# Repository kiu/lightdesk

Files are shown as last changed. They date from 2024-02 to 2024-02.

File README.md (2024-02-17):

# lightdesk

Custom desk light and RGB strip controller

Superseded by [https://github.com/kiu/kha](https://github.com/kiu/kha)

## Photos

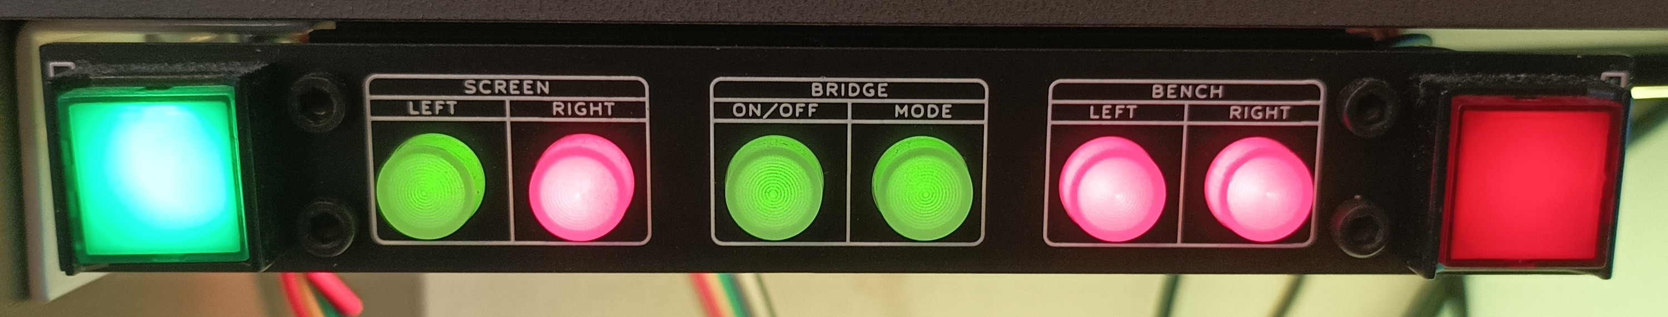
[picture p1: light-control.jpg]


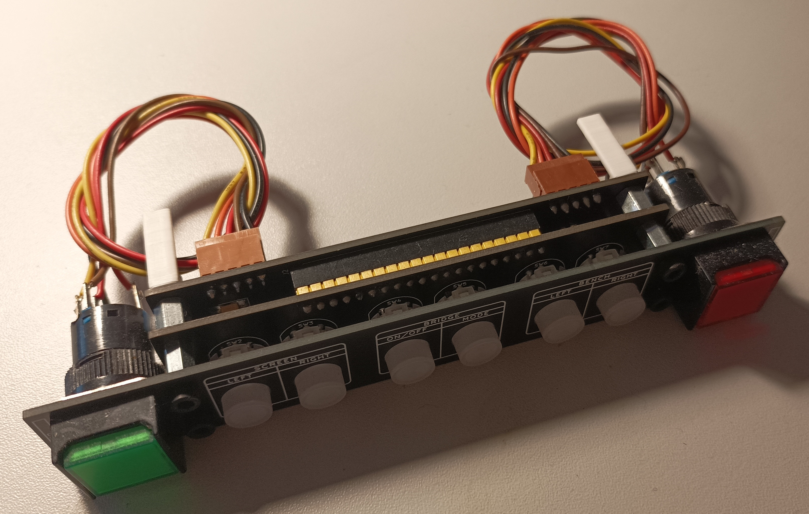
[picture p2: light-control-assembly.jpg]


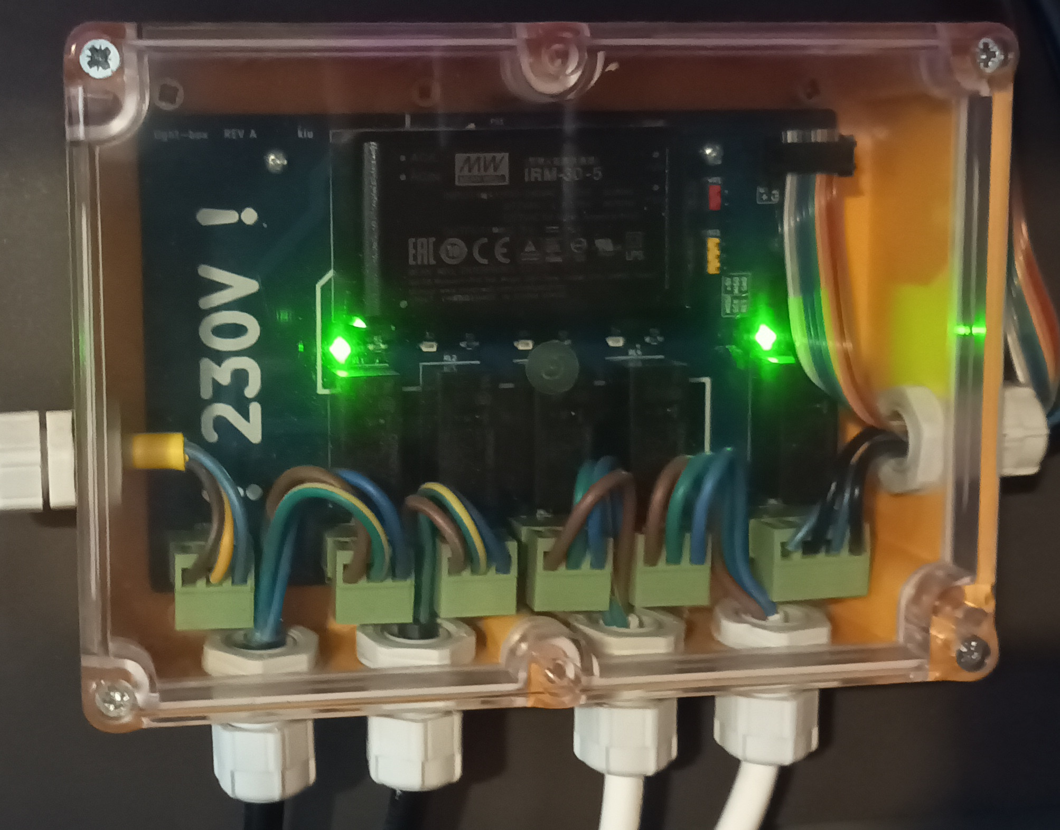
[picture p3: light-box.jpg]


## Render

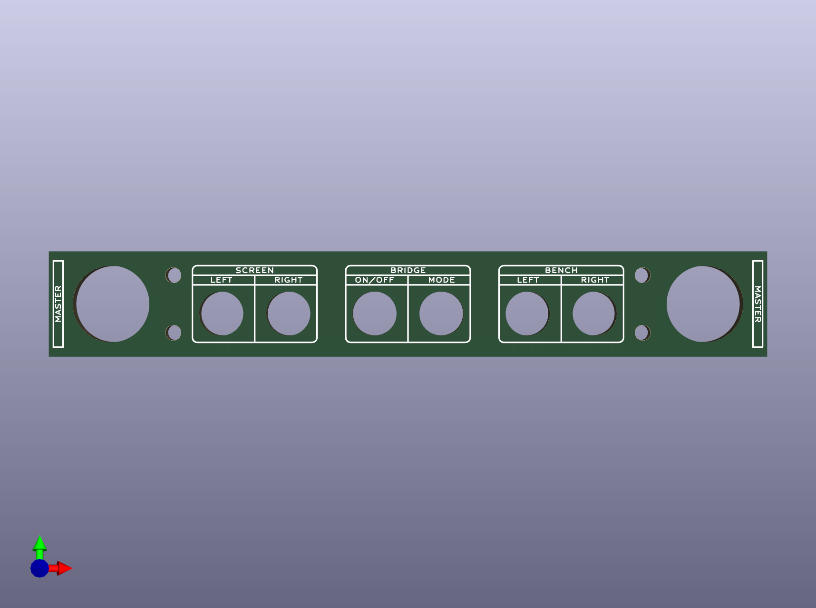
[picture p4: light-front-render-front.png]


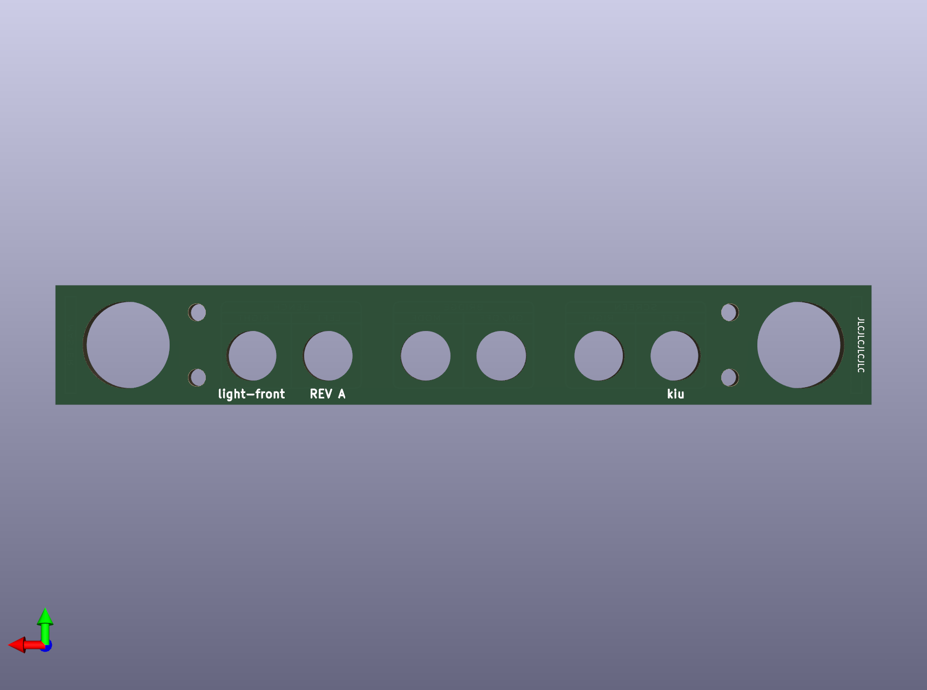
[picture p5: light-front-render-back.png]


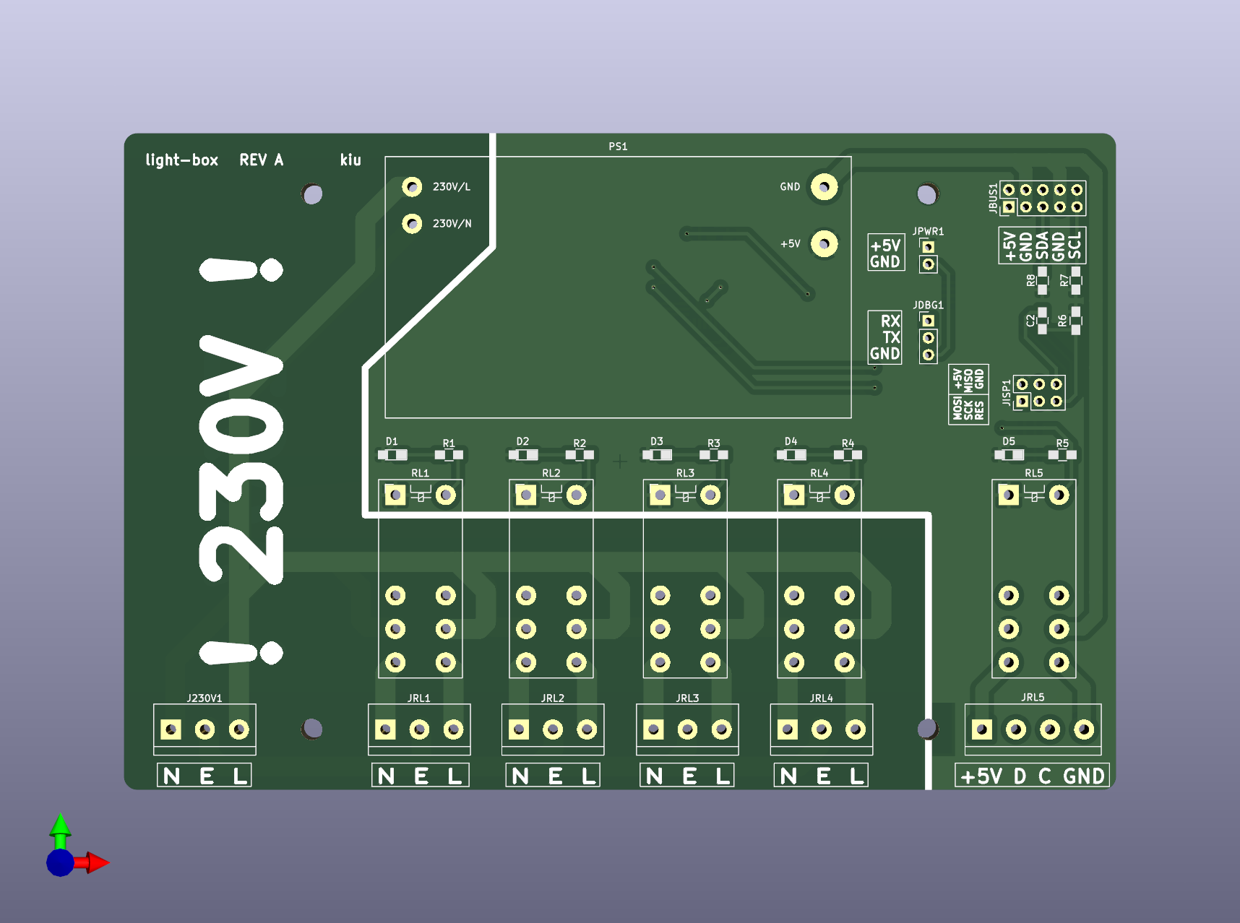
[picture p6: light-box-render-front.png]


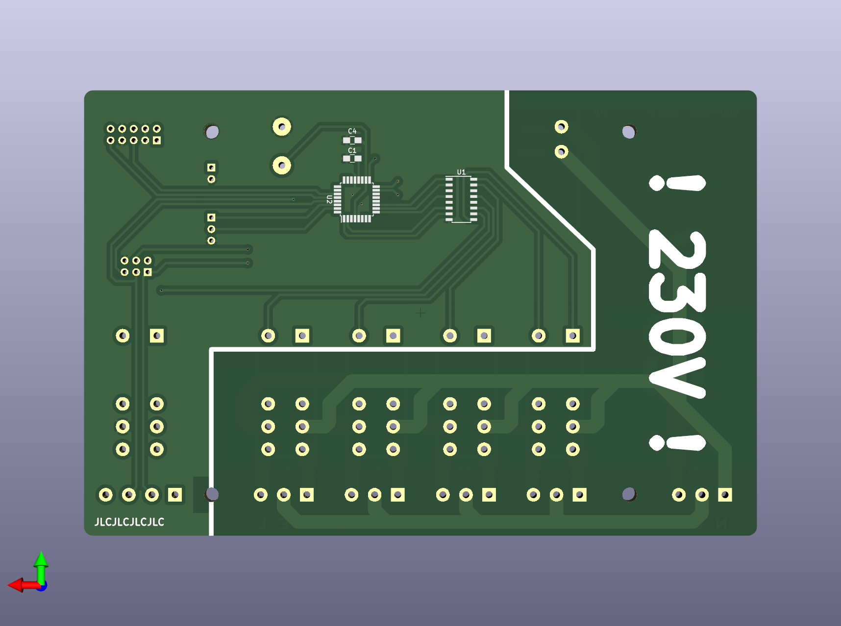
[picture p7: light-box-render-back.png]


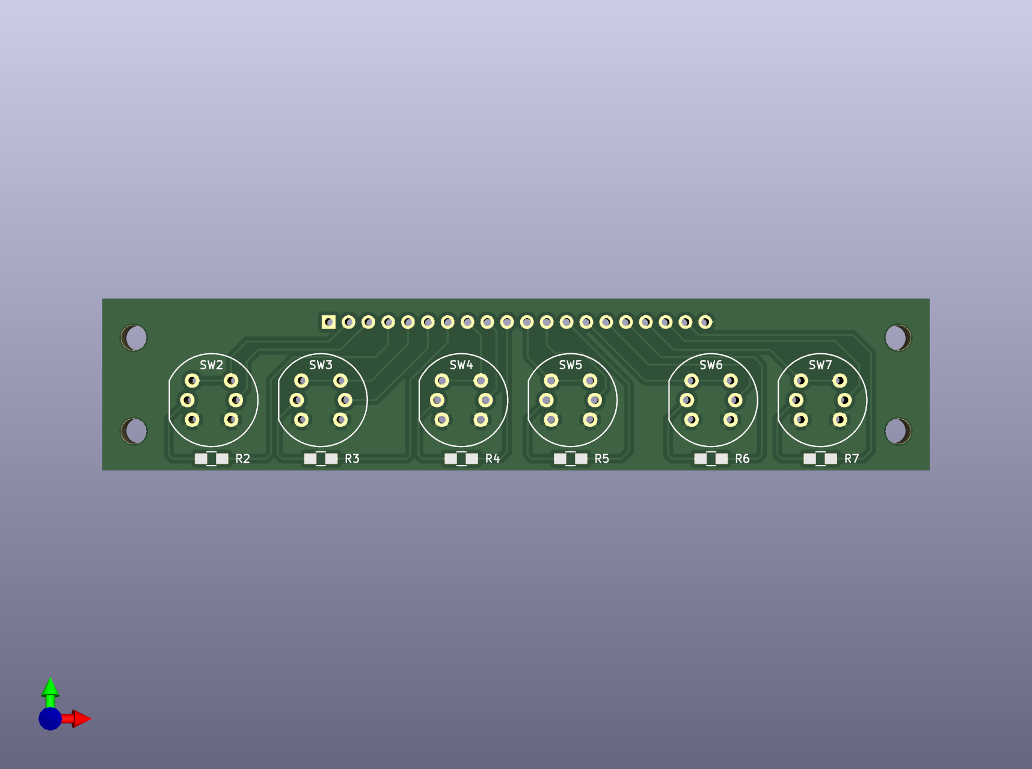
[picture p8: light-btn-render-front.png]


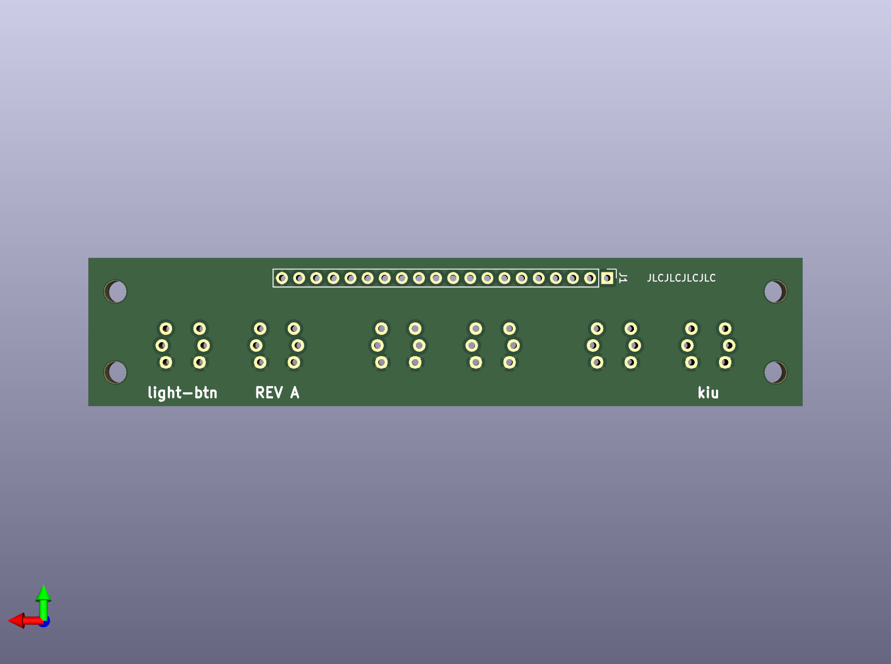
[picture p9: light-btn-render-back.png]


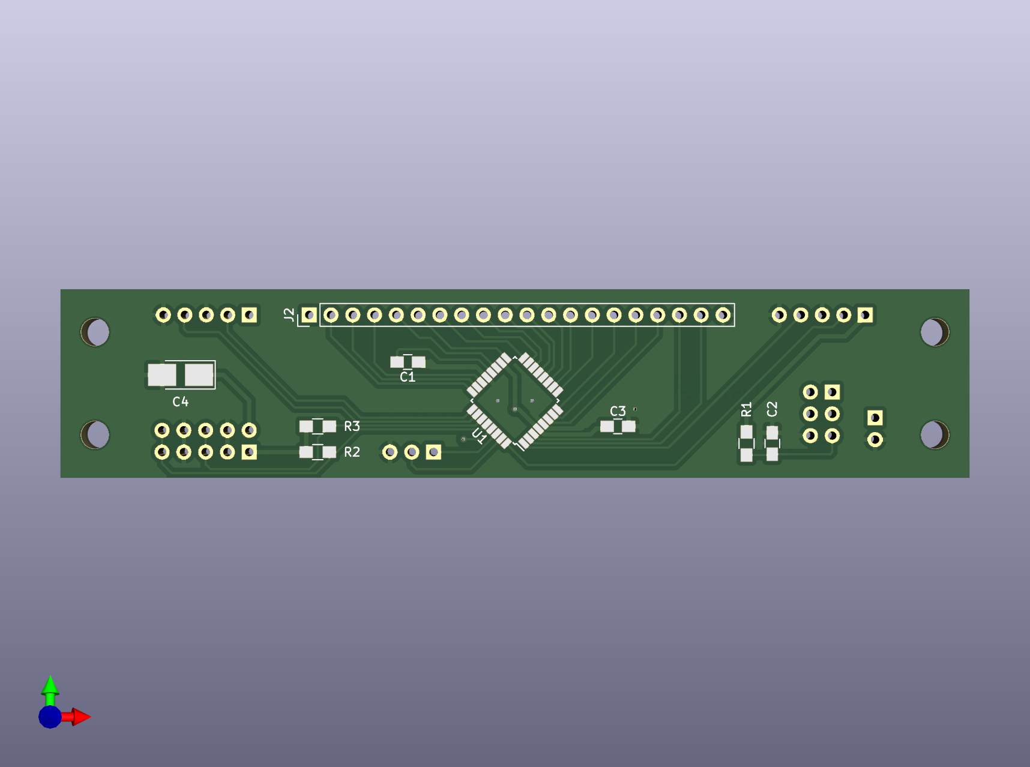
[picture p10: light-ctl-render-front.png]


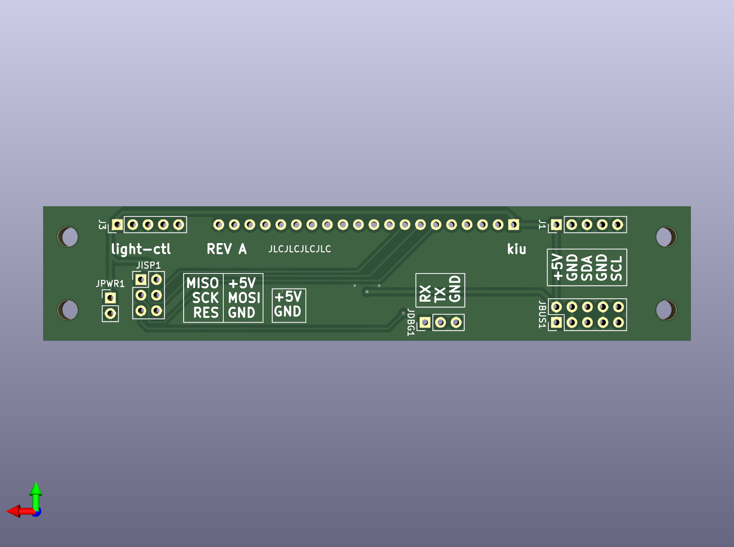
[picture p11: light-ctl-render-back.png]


# License

This project is licensed under the Creative Commons Attribution-NonCommercial 3.0 Unported (CC BY-NC 3.0) license.

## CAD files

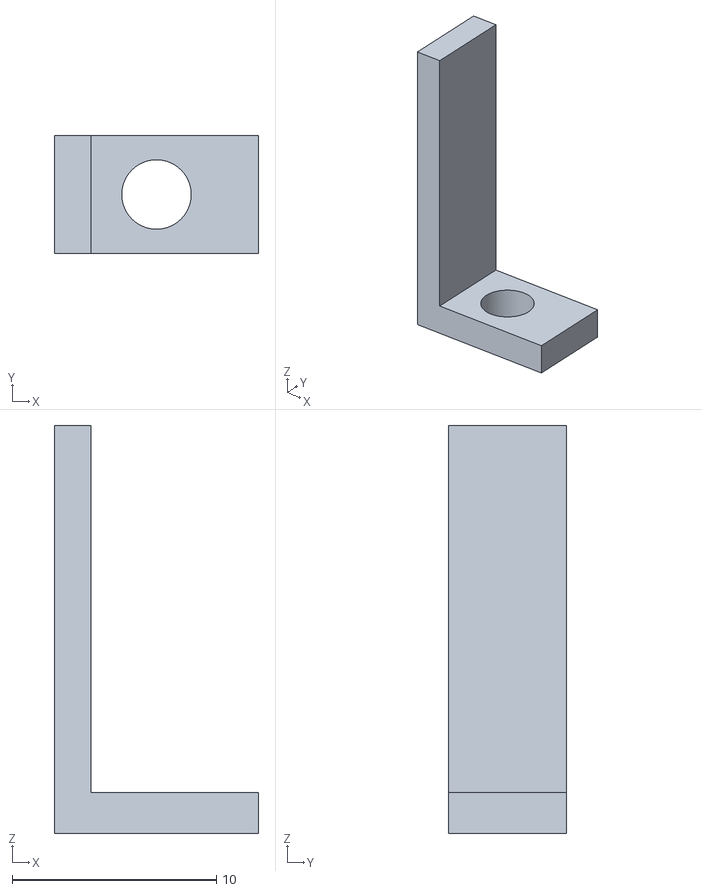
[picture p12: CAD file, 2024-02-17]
mechanical/desklight-a.stl
10.0 x 5.80 x 20.0

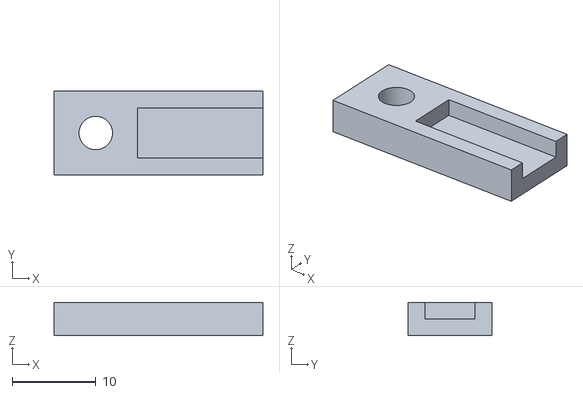
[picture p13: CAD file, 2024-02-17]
mechanical/desklight-b.stl
25.0 x 10.0 x 4.00

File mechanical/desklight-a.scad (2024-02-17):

difference () {
    translate([0, -2.9, 0]) { 
        cube([10, 5.8, 2]);
    }

    translate([5, 0, 0]) { 
        cylinder(h=15, r=1.7, $fn = 360, center=true);
    }
}

translate([0, -2.9, 0]) {
    cube([1.8, 5.8, 20]);  
}

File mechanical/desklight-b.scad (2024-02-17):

difference () {
    translate([0, -5, 0]) { 
        cube([25, 10, 4]);
    }

    translate([5, 0, 0]) { 
        cylinder(h=15, d=4, $fn = 360, center=true);
    }
    
//    translate([5, 0, 0]) { 
//        cylinder(h=3, r1=3.5, r2=1.3, $fn = 360, center=true);
//    }
    
    
    translate([10, -3, 2]) { 
        cube([16, 6, 3]);
    }
}

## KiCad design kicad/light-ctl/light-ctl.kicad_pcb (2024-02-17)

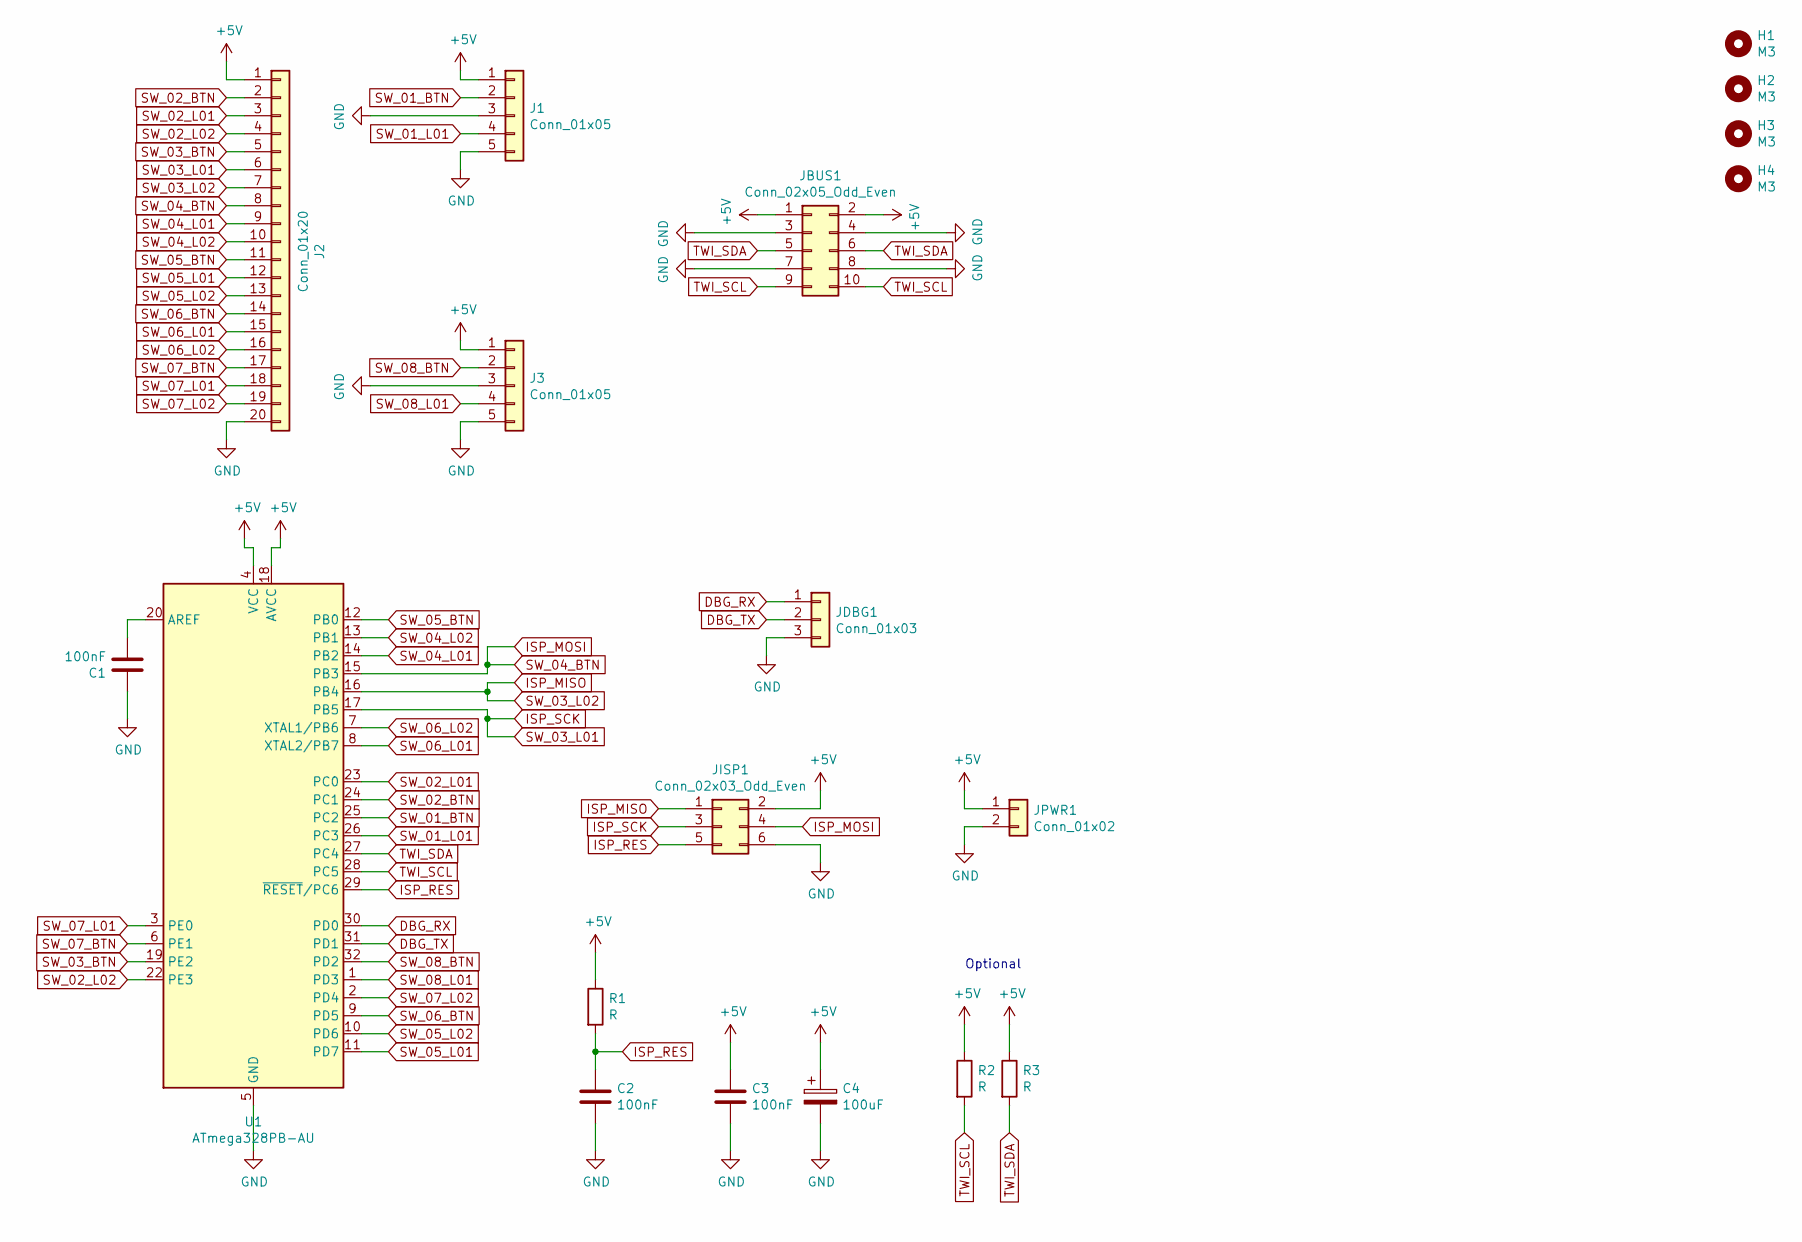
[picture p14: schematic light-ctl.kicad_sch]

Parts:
C1, C2, C3: 100nF; C_0805_HandSoldering
C4: 100uF; CP_Tantalum_Case-B_EIA-3528-21_Hand
H1, H2, H3, H4: M3; MountingHole_3.2mm_M3_DIN965
J1, J3: Conn_01x05; Pin_Header_Straight_1x05_Pitch2.54mm
J2: Conn_01x20; Pin_Header_Straight_1x20_Pitch2.54mm
JBUS1: Conn_02x05_Odd_Even; Pin_Header_Straight_2x05_Pitch2.54mm
JDBG1: Conn_01x03; Pin_Header_Straight_1x03_Pitch2.54mm
JISP1: Conn_02x03_Odd_Even; Pin_Header_Straight_2x03_Pitch2.54mm
JPWR1: Conn_01x02; Pin_Header_Straight_1x02_Pitch2.54mm
R1, R2, R3: R; R_0805_HandSoldering
U1: ATmega328PB-AU; LQFP-32_7x7mm_Pitch0.8mm

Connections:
+5V: C3.1, C4.1, J1.1, J2.1, J3.1, JBUS1.1, JBUS1.2, JISP1.2, JPWR1.1, R1.1, R2.1, R3.1, U1.4 (VCC), U1.18 (AVCC)
DBG_RX: JDBG1.1, U1.30 (PD0)
DBG_TX: JDBG1.2, U1.31 (PD1)
GND: C1.1, C2.2, C3.2, C4.2, J1.3, J1.5, J2.20, J3.3, J3.5, JBUS1.3, JBUS1.4, JBUS1.7, JBUS1.8, JDBG1.3, JISP1.6, JPWR1.2, U1.5 (GND), U1.21 (GND)
ISP_MISO: J2.7, JISP1.1, U1.16 (PB4)
ISP_MOSI: J2.8, JISP1.4, U1.15 (PB3)
ISP_RES: C2.1, JISP1.5, R1.2, U1.29 (~RESET/PC6)
ISP_SCK: J2.6, JISP1.3, U1.17 (PB5)
unnamed: C1.2, U1.20 (AREF)
SW_01_BTN: J1.2, U1.25 (PC2)
SW_01_L01: J1.4, U1.26 (PC3)
SW_02_BTN: J2.2, U1.24 (PC1)
SW_02_L01: J2.3, U1.23 (PC0)
SW_02_L02: J2.4, U1.22 (PE3)
SW_03_BTN: J2.5, U1.19 (PE2)
SW_04_L01: J2.9, U1.14 (PB2)
SW_04_L02: J2.10, U1.13 (PB1)
SW_05_BTN: J2.11, U1.12 (PB0)
SW_05_L01: J2.12, U1.11 (PD7)
SW_05_L02: J2.13, U1.10 (PD6)
SW_06_BTN: J2.14, U1.9 (PD5)
SW_06_L01: J2.15, U1.8 (XTAL2/PB7)
SW_06_L02: J2.16, U1.7 (XTAL1/PB6)
SW_07_BTN: J2.17, U1.6 (PE1)
SW_07_L01: J2.18, U1.3 (PE0)
SW_07_L02: J2.19, U1.2 (PD4)
SW_08_BTN: J3.2, U1.32 (PD2)
SW_08_L01: J3.4, U1.1 (PD3)
TWI_SCL: JBUS1.9, JBUS1.10, R2.2, U1.28 (PC5)
TWI_SDA: JBUS1.5, JBUS1.6, R3.2, U1.27 (PC4)

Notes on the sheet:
Optional

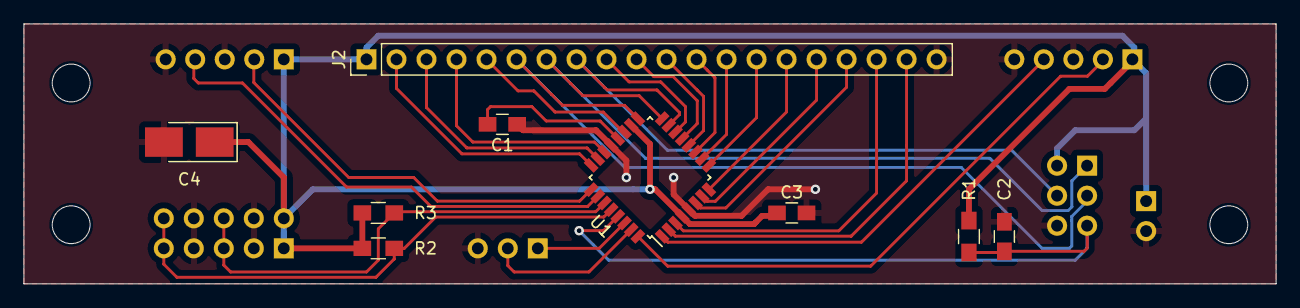
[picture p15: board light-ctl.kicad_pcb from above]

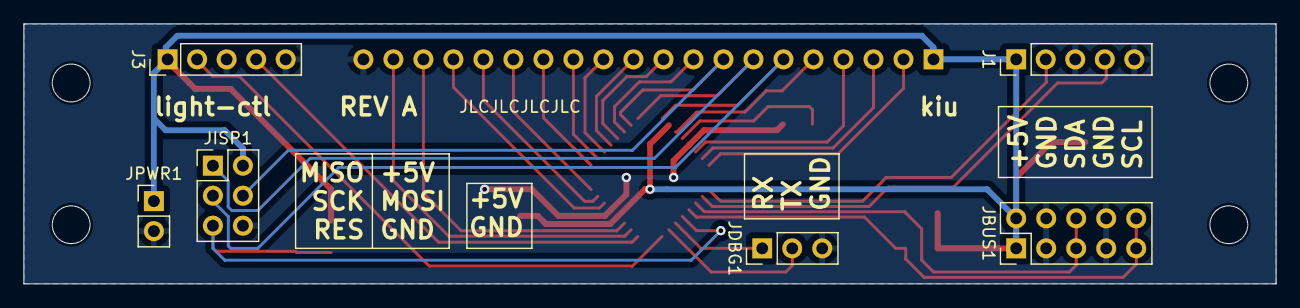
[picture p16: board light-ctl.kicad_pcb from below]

Board: 2 copper layers, 106.0 x 22.0 mm, 19 parts (6 on the bottom side), 30 nets.

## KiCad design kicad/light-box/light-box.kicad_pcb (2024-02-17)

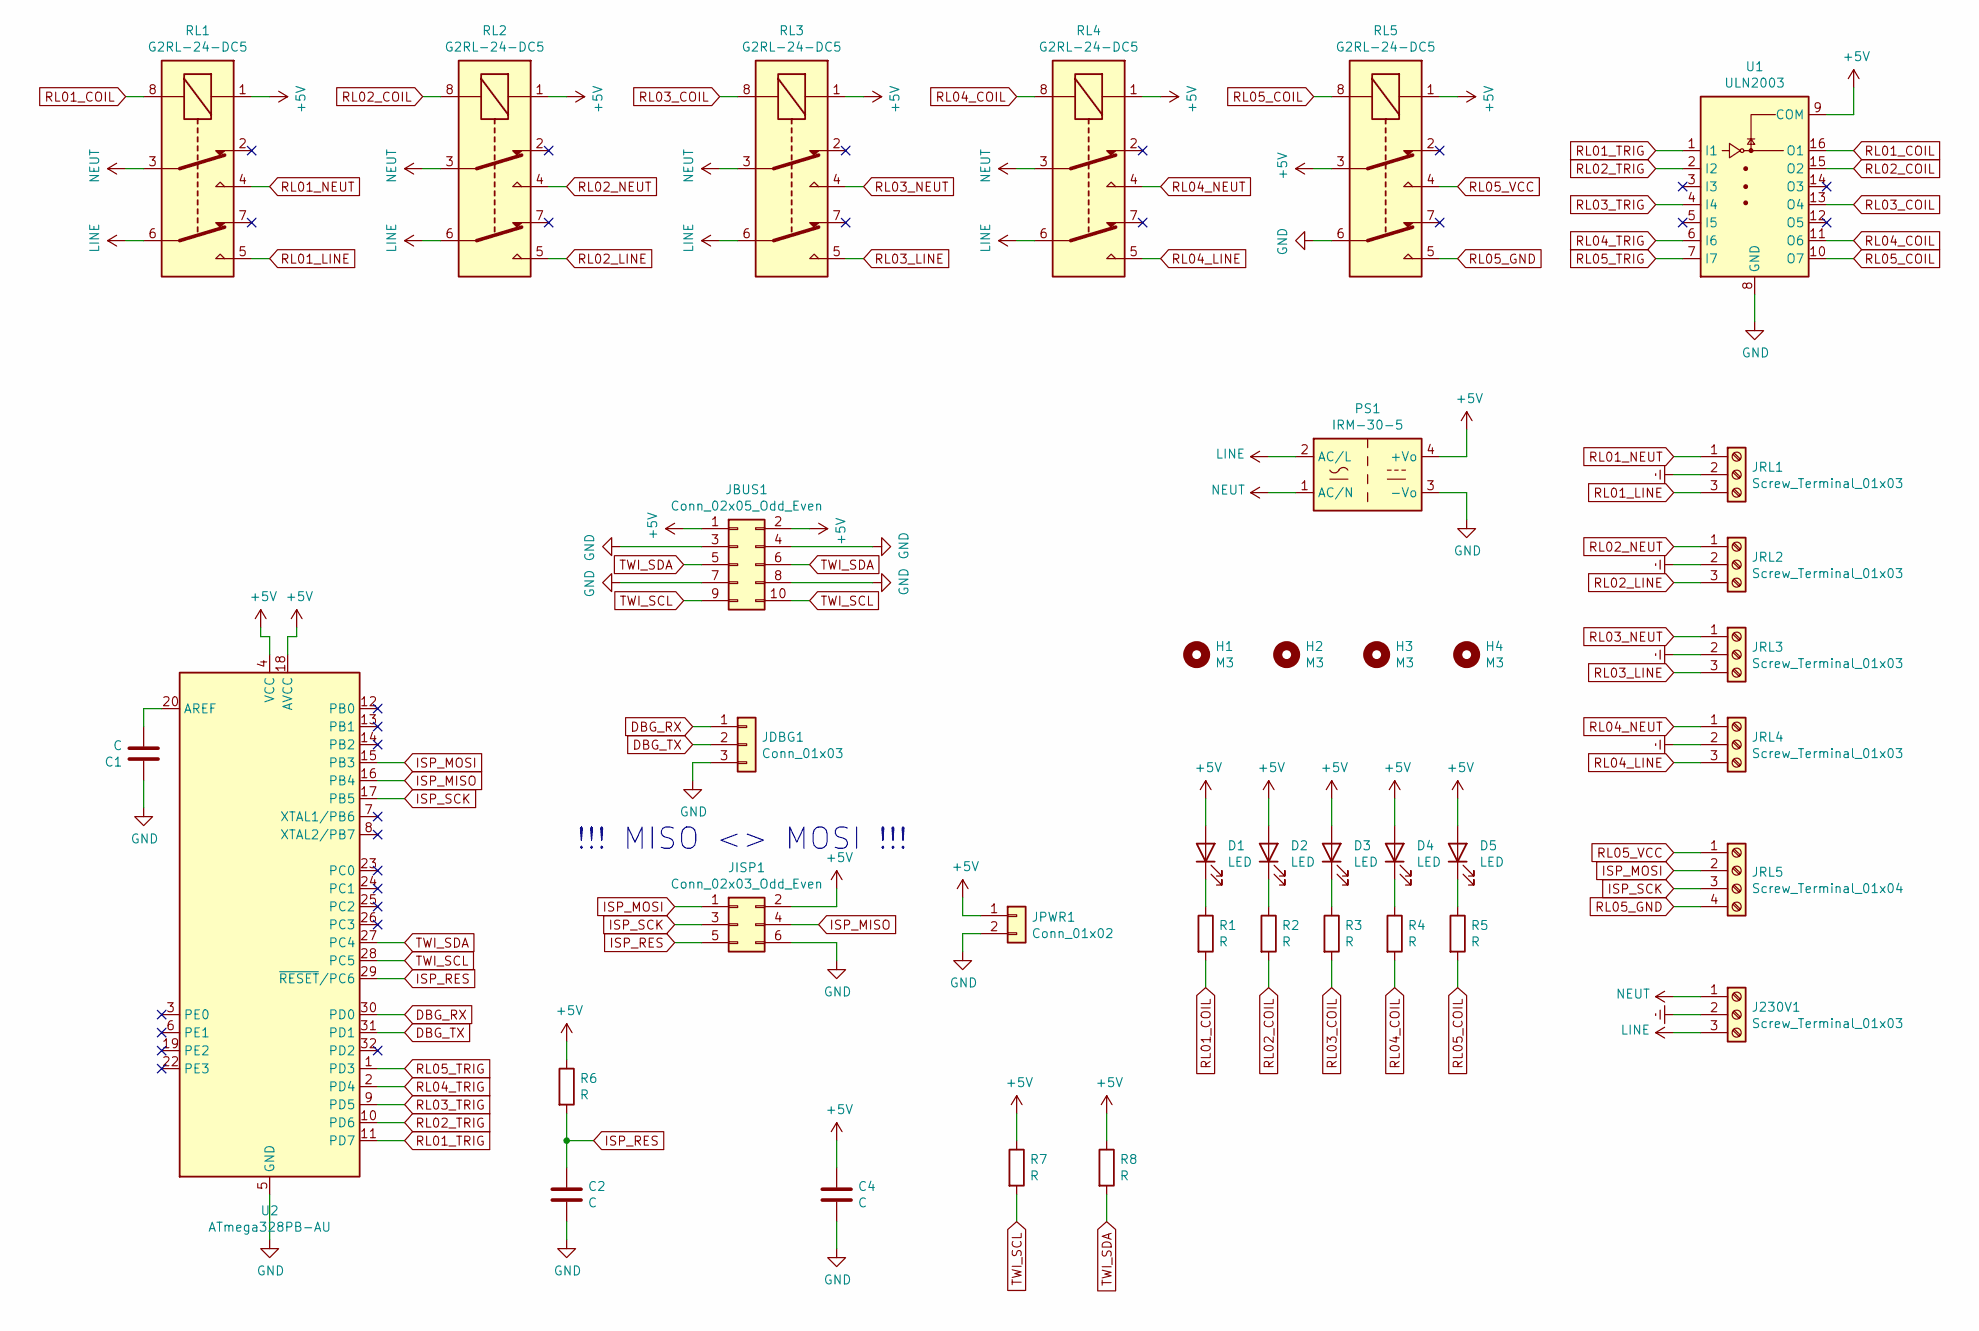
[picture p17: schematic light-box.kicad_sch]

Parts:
C1, C2, C4: C; C_0805_HandSoldering
D1, D2, D3, D4, D5: LED; LED_0805_HandSoldering
H1, H2, H3, H4: M3; MountingHole_3.2mm_M3_DIN965
J230V1: Screw_Terminal_01x03; TerminalBlock_bornier-3_P5.08mm
JBUS1: Conn_02x05_Odd_Even; Pin_Header_Straight_2x05_Pitch2.54mm
JDBG1: Conn_01x03; Pin_Header_Straight_1x03_Pitch2.54mm
JISP1: Conn_02x03_Odd_Even; Pin_Header_Straight_2x03_Pitch2.54mm
JPWR1: Conn_01x02; Pin_Header_Straight_1x02_Pitch2.54mm
JRL1, JRL2, JRL3, JRL4: Screw_Terminal_01x03; TerminalBlock_bornier-3_P5.08mm
JRL5: Screw_Terminal_01x04; TerminalBlock_bornier-4_P5.08mm
PS1: IRM-30-5; ACDC-Conv_MeanWell-IRM-30-XX
R1, R2, R3, R4, R5, R6, R7, R8: R; R_0805_HandSoldering
RL1, RL2, RL3, RL4, RL5: G2RL-24-DC5; Relay_DPDT_Omron_G2RL-24
U1: ULN2003; SOIC-16_3.9x9.9mm_Pitch1.27mm
U2: ATmega328PB-AU; TQFP-32_7x7mm_Pitch0.8mm

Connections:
+5V: C4.1, D1.2 (A), D2.2 (A), D3.2 (A), D4.2 (A), D5.2 (A), JBUS1.1, JBUS1.2, JISP1.2, JPWR1.1, PS1.4 (+Vo), R6.1, R7.1, R8.1, RL1.1, RL2.1, RL3.1, RL4.1, RL5.1, RL5.3, U1.9 (COM), U2.4 (VCC), U2.18 (AVCC)
DBG_RX: JDBG1.1, U2.30 (PD0)
DBG_TX: JDBG1.2, U2.31 (PD1)
Earth: J230V1.2, JRL1.2, JRL2.2, JRL3.2, JRL4.2
GND: C1.1, C2.2, C4.2, JBUS1.3, JBUS1.4, JBUS1.7, JBUS1.8, JDBG1.3, JISP1.6, JPWR1.2, PS1.3 (-Vo), RL5.6, U1.8 (GND), U2.5 (GND), U2.21 (GND)
ISP_MISO: JISP1.4, U2.16 (PB4)
ISP_MOSI: JISP1.1, JRL5.2, U2.15 (PB3)
ISP_RES: C2.1, JISP1.5, R6.2, U2.29 (~RESET/PC6)
ISP_SCK: JISP1.3, JRL5.3, U2.17 (PB5)
LINE: J230V1.3, PS1.2 (AC/L), RL1.6, RL2.6, RL3.6, RL4.6
NEUT: J230V1.1, PS1.1 (AC/N), RL1.3, RL2.3, RL3.3, RL4.3
unnamed: C1.2, U2.20 (AREF)
unnamed: D1.1 (K), R1.1
unnamed: D2.1 (K), R2.1
unnamed: D3.1 (K), R3.1
unnamed: D4.1 (K), R4.1
unnamed: D5.1 (K), R5.1
RL01_COIL: R1.2, RL1.8, U1.16 (O1)
RL01_LINE: JRL1.3, RL1.5
RL01_NEUT: JRL1.1, RL1.4
RL01_TRIG: U1.1 (I1), U2.11 (PD7)
RL02_COIL: R2.2, RL2.8, U1.15 (O2)
RL02_LINE: JRL2.3, RL2.5
RL02_NEUT: JRL2.1, RL2.4
RL02_TRIG: U1.2 (I2), U2.10 (PD6)
RL03_COIL: R3.2, RL3.8, U1.13 (O4)
RL03_LINE: JRL3.3, RL3.5
RL03_NEUT: JRL3.1, RL3.4
RL03_TRIG: U1.4 (I4), U2.9 (PD5)
RL04_COIL: R4.2, RL4.8, U1.11 (O6)
RL04_LINE: JRL4.3, RL4.5
RL04_NEUT: JRL4.1, RL4.4
RL04_TRIG: U1.6 (I6), U2.2 (PD4)
RL05_COIL: R5.2, RL5.8, U1.10 (O7)
RL05_GND: JRL5.4, RL5.5
RL05_TRIG: U1.7 (I7), U2.1 (PD3)
RL05_VCC: JRL5.1, RL5.4
TWI_SCL: JBUS1.9, JBUS1.10, R7.2, U2.28 (PC5)
TWI_SDA: JBUS1.5, JBUS1.6, R8.2, U2.27 (PC4)

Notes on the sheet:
!!! MISO <> MOSI !!!

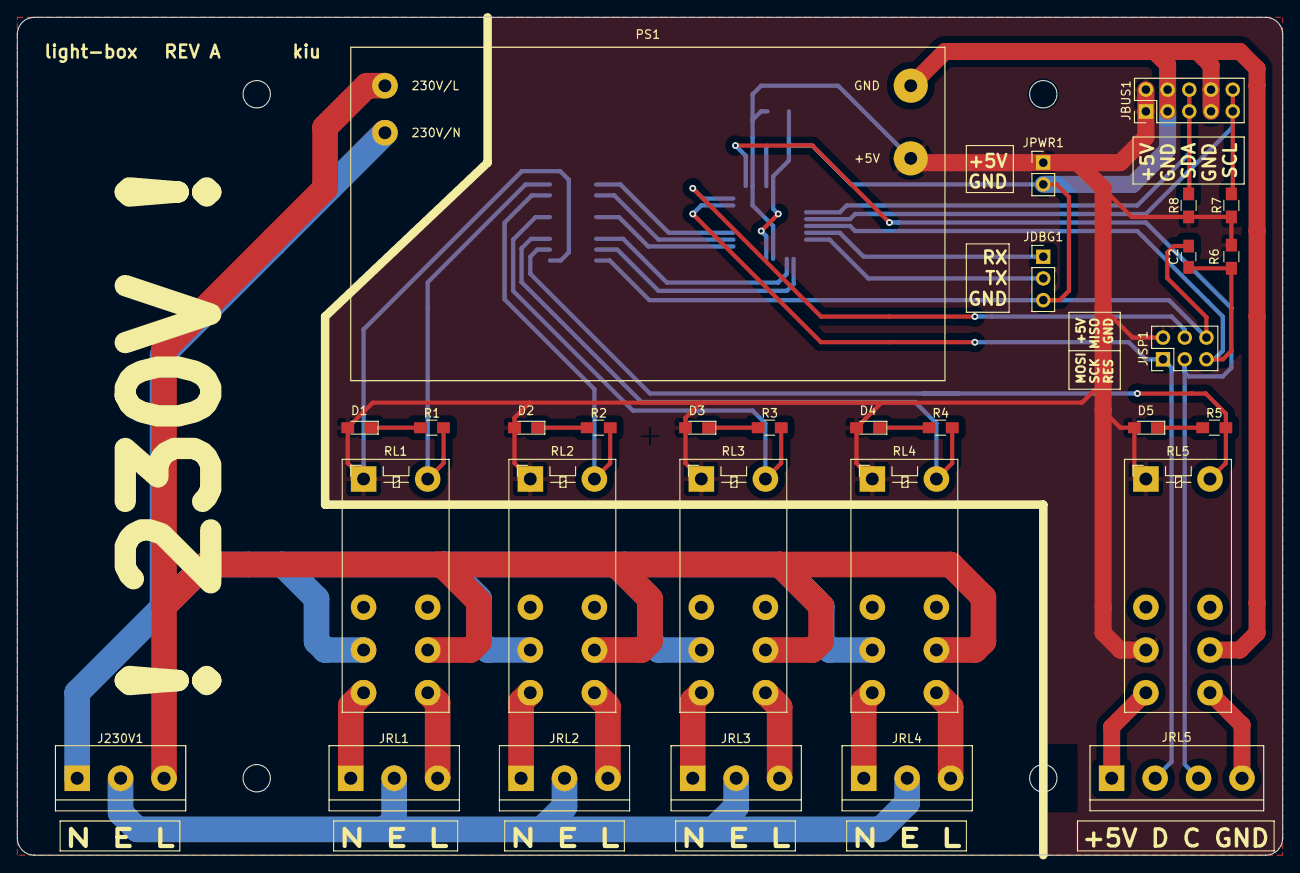
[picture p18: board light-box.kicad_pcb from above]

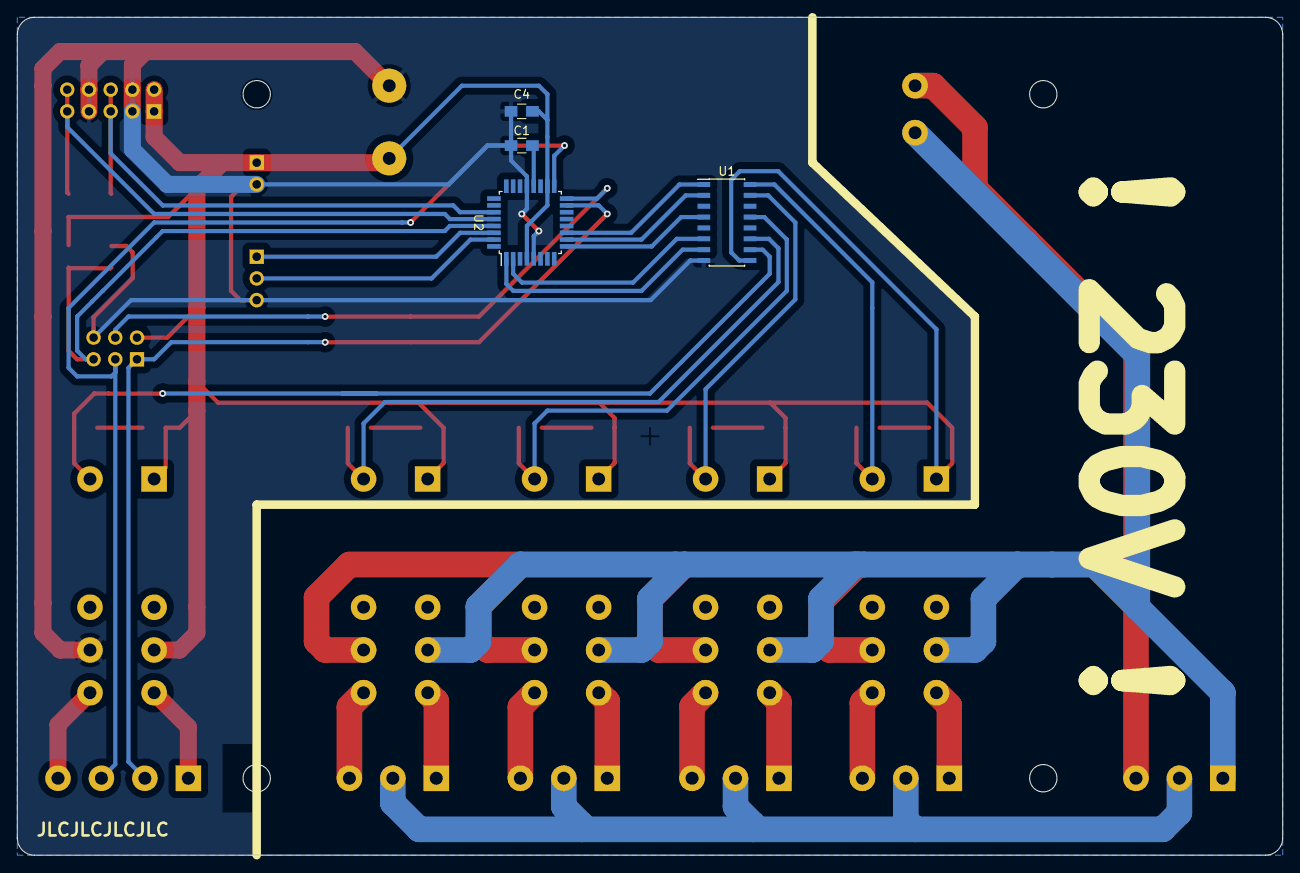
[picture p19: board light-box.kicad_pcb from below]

Board: 2 copper layers, 148.0 x 98.0 mm, 38 parts (4 on the bottom side), 39 nets.

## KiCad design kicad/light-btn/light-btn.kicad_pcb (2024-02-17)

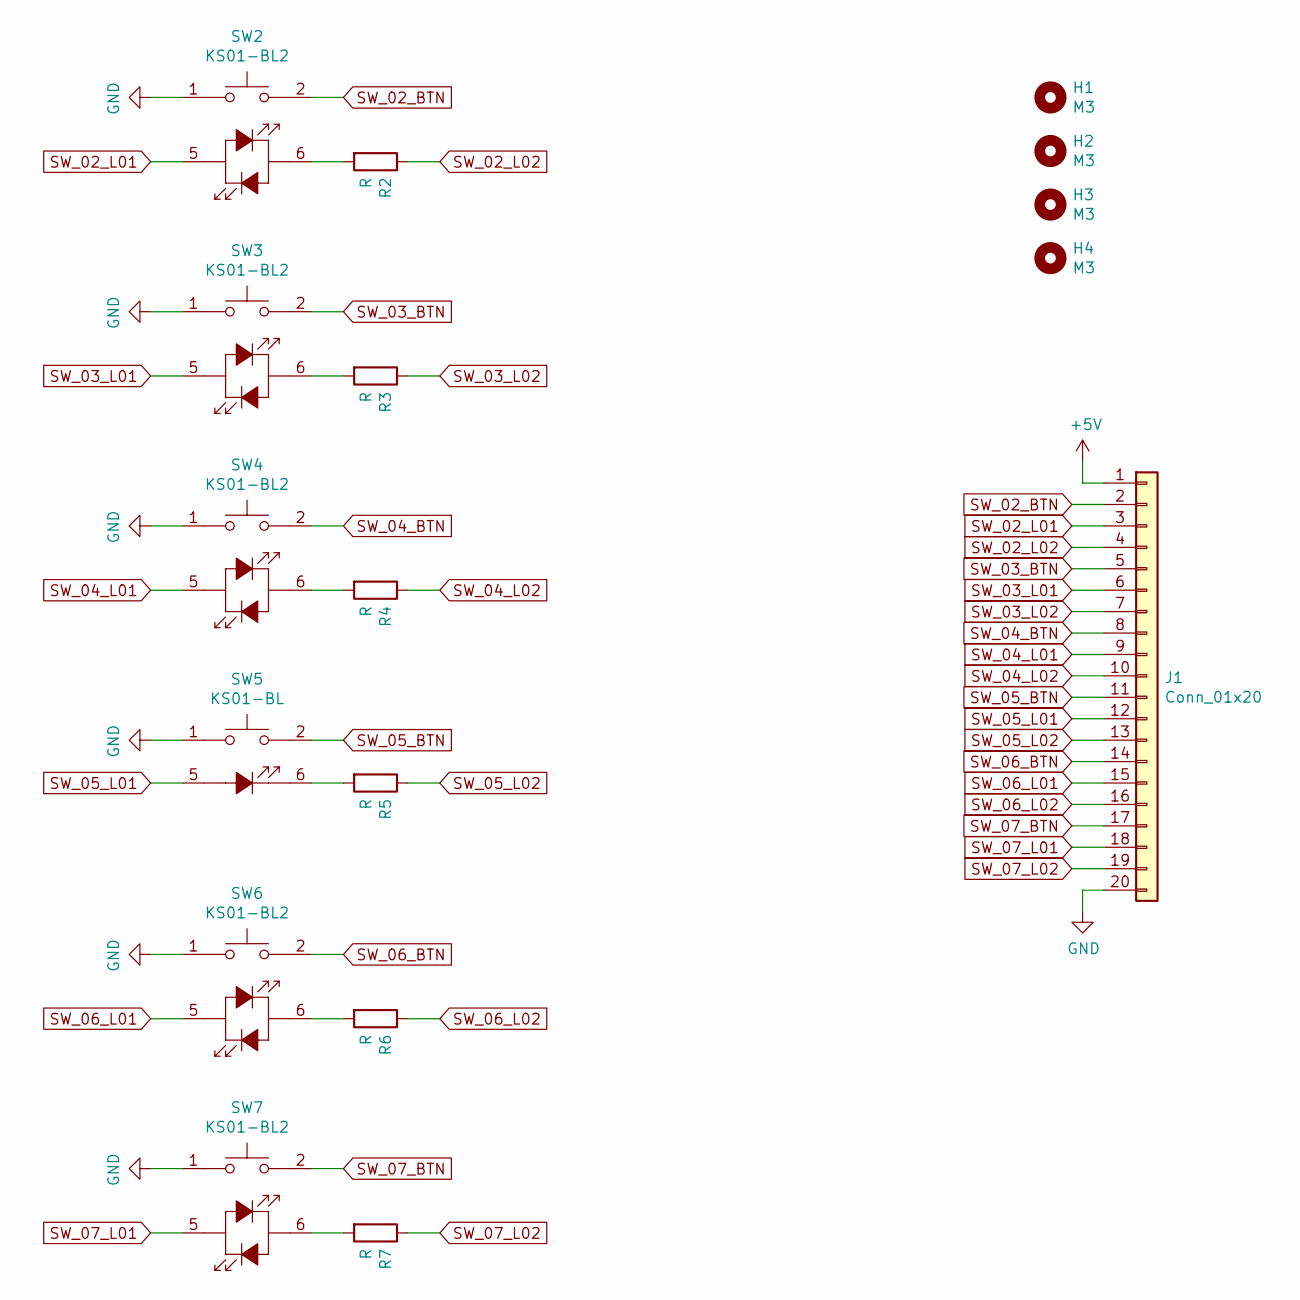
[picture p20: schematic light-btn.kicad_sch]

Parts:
H1, H2, H3, H4: M3; MountingHole_3.2mm_M3_DIN965
J1: Conn_01x20; Pin_Header_Straight_1x20_Pitch2.54mm
R2, R3, R4, R5, R6, R7: R; R_0805_HandSoldering
SW2, SW3, SW4, SW6, SW7: KS01-BL2; KS01-BL
SW5: KS01-BL

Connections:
GND: J1.20, SW2.1, SW3.1, SW4.1, SW5.1, SW6.1, SW7.1
unnamed: R2.2, SW2.6
unnamed: R3.2, SW3.6
unnamed: R4.2, SW4.6
unnamed: R5.2, SW5.6
unnamed: R6.2, SW6.6
unnamed: R7.2, SW7.6
SW_02_BTN: J1.2, SW2.2
SW_02_L01: J1.3, SW2.5
SW_02_L02: J1.4, R2.1
SW_03_BTN: J1.5, SW3.2
SW_03_L01: J1.6, SW3.5
SW_03_L02: J1.7, R3.1
SW_04_BTN: J1.8, SW4.2
SW_04_L01: J1.9, SW4.5
SW_04_L02: J1.10, R4.1
SW_05_BTN: J1.11, SW5.2
SW_05_L01: J1.12, SW5.5
SW_05_L02: J1.13, R5.1
SW_06_BTN: J1.14, SW6.2
SW_06_L01: J1.15, SW6.5
SW_06_L02: J1.16, R6.1
SW_07_BTN: J1.17, SW7.2
SW_07_L01: J1.18, SW7.5
SW_07_L02: J1.19, R7.1

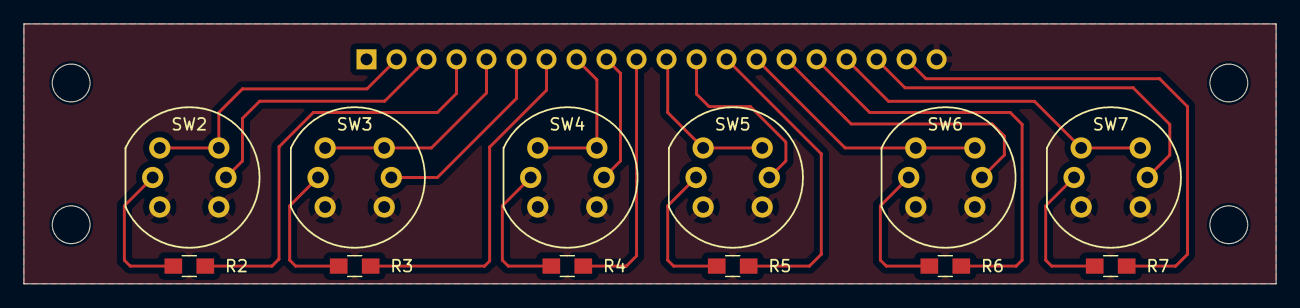
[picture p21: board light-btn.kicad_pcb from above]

Board: 2 copper layers, 106.0 x 22.0 mm, 17 parts (1 on the bottom side), 25 nets.

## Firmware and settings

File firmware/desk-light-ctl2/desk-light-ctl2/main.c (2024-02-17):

#include <atmel_start.h>
#include <i2c_simple_master.h>
#include <util/delay.h>

// [] | O | O | O | O | O | O | []	// panel

//  0 | 1 | 2 | 3 | 4 | 5 | 6 | 7	// button
//  1 | 2 | 3 | 4 | 5 | 6 | 7 | 8	// button io
//  - | 0 | 1 | 4 | - | 2 | 3 | -	// relay

typedef enum {INIT, IDLE, POWER_UP, POWER_DOWN_WAIT, POWER_DOWN} system_mode_t;
const char *system_mode_names[] = { "INIT", "IDLE", "POWER_UP", "POWER_DOWN_WAIT", "POWER_DOWN"};
const uint8_t order_power_up[] = {0, 1, 2, 3};
const uint8_t order_power_down[] = {3, 2, 4, 1, 0};

system_mode_t system_mode = INIT;
uint8_t system_mode_count;
volatile bool system_blink;

bool (*fp_btn[8])() = {SW_01_BTN_get_level, SW_02_BTN_get_level, SW_03_BTN_get_level, SW_04_BTN_get_level, SW_05_BTN_get_level, SW_06_BTN_get_level, SW_07_BTN_get_level, SW_08_BTN_get_level};
volatile uint8_t btn_timeout[8];
volatile bool btn_state[8];

bool relay_state[5];

bool i2c_send = true;

const uint8_t PGM_STATE_MAX = 0x02;
uint8_t pgm_state = 0x00;
uint8_t pgm_flash = 0;

const uint8_t I2C_SLAVE = 0x42;

// ------------------------------------------------------------------------------------

#define BYTE_TO_BINARY_PATTERN "%c%c%c%c%c%c%c%c"
#define BYTE_TO_BINARY(byte) (byte & 0x80 ? '1' : '0'), (byte & 0x40 ? '1' : '0'), (byte & 0x20 ? '1' : '0'), (byte & 0x10 ? '1' : '0'), (byte & 0x08 ? '1' : '0'), (byte & 0x04 ? '1' : '0'), (byte & 0x02 ? '1' : '0'), (byte & 0x01 ? '1' : '0')

bool power_up_ready() {
	return !(relay_state[0] & relay_state [1] & relay_state [2] & relay_state [3]);
}

bool power_down_ready() {
	return (relay_state[0] | relay_state [1] | relay_state [2] | relay_state [3] | relay_state[4]);
}

// ------------------------------------------------------------------------------------

volatile uint8_t pwm = 0;
volatile uint16_t led = 0x00;

void setLED(uint8_t n, uint8_t val) {
	if (val) {
		led = led | (1 << n);
		} else {
		led = led & ~(1<< n);
	}
}

void test() {
	pwm++;
	if (pwm == 100) {
		pwm = 0;
	}
	if (pwm == 0) {
		if (led & 0x01 << 0) {
			SW_01_L01_set_level(true);
		}
		if (led & 0x01 << 1) {
			SW_02_L01_set_level(true);
		}
		if (led & 0x01 << 2) {
			SW_02_L02_set_level(true);
		}
		if (led & 0x01 << 3) {
			SW_03_L01_set_level(true);
		}
		if (led & 0x01 << 4) {
			SW_03_L02_set_level(true);
		}
		if (led & 0x01 << 5) {
			SW_04_L01_set_level(true);
		}
		if (led & 0x01 << 6) {
			SW_04_L02_set_level(true);
		}
		if (led & 0x01 << 7) {
			SW_05_L01_set_level(true);
		}
		if (led & 0x01 << 8) {
			SW_05_L02_set_level(true);
		}
		if (led & 0x01 << 9) {
			SW_06_L01_set_level(true);
		}
		if (led & 0x01 << 10) {
			SW_06_L02_set_level(true);
		}
		if (led & 0x01 << 11) {
			SW_07_L01_set_level(true);
		}
		if (led & 0x01 << 12) {
			SW_07_L02_set_level(true);
		}
		if (led & 0x01 << 13) {
			SW_08_L01_set_level(true);
		}
	}
	if (pwm == 14) {
		SW_01_L01_set_level(false);
		
		SW_02_L01_set_level(false);
		SW_02_L02_set_level(false);

		SW_03_L01_set_level(false);
		SW_03_L02_set_level(false);

		SW_04_L01_set_level(false);
		SW_04_L02_set_level(false);

		SW_05_L01_set_level(false);
		SW_05_L02_set_level(false);

		SW_06_L01_set_level(false);
		SW_06_L02_set_level(false);

		SW_07_L01_set_level(false);
		SW_07_L02_set_level(false);
		
		SW_08_L01_set_level(false);
	}
}


void relay_set(uint8_t rly, bool on) {
	printf("Relay %d set to %d \n", rly, on);
	
	if (relay_state[rly] != on) {
		i2c_send = true;
	}
	relay_state[rly] = on;
	
	if (system_mode == IDLE) {
		//SW_01_L01_set_level(power_up_ready());
		//SW_08_L01_set_level(power_down_ready());
		setLED(0, power_up_ready());
		setLED(13, power_down_ready());
	}
	
	bool L01 = on ? false : true;
	bool L02 = on ? true : false;
	
	switch (rly) {
		case 0:
		//		SW_02_L01_set_level(L01);
		//		SW_02_L02_set_level(L02);
		setLED(1, L01);
		setLED(2, L02);
		break;

		case 1:
		//		SW_03_L01_set_level(L01);
		//		SW_03_L02_set_level(L02);
		setLED(3, L01);
		setLED(4, L02);
		break;

		case 2:
		//		SW_06_L01_set_level(L01);
		//		SW_06_L02_set_level(L02);
		setLED(9, L01);
		setLED(10, L02);
		break;

		case 3:
		//		SW_07_L01_set_level(L01);
		//		SW_07_L02_set_level(L02);
		setLED(11, L01);
		setLED(12, L02);
		break;

		case 4:
		//		SW_04_L01_set_level(L01);
		//		SW_04_L02_set_level(L02);
		setLED(5, L01);
		setLED(6, L02);

		//		SW_05_L01_set_level(L01);
		//		SW_05_L02_set_level(L02);
		setLED(7, L01);
		setLED(8, L02);
		break;
	}
}

void relay_toggle(uint8_t rly) {
	relay_set(rly, !relay_state[rly]);
}

// ------------------------------------------------------------------------------------

void system_mode_change(system_mode_t mode) {
	printf("System mode change from %s to %s\n", system_mode_names[system_mode], system_mode_names[mode]);
	
	system_mode_count = 0;
	
	if (mode == IDLE) {
		//		SW_01_L01_set_level(power_up_ready());
		//		SW_08_L01_set_level(power_down_ready());
		setLED(0, power_up_ready());
		setLED(13, power_down_ready());

		system_mode = mode;
	}
	if (mode == POWER_UP) {
		//	SW_01_L01_set_level(system_blink);
		//		SW_08_L01_set_level(true);
		setLED(0, system_blink);
		setLED(13, true);
		system_mode = mode;
	}
	if (mode == POWER_DOWN_WAIT) {
		//		SW_01_L01_set_level(true);
		//		SW_08_L01_set_level(system_blink);
		setLED(0, true);
		setLED(13, system_blink);
		system_mode = mode;
	}
	if (mode == POWER_DOWN) {
		//SW_01_L01_set_level(true);
		//SW_08_L01_set_level(system_blink);
		setLED(0, true);
		setLED(13, system_blink);
		system_mode = mode;
	}
}

void system_mode_tick() {
	system_mode_count++;

	if (system_mode == POWER_UP) {
		//SW_01_L01_set_level(system_blink);
		setLED(0, system_blink);
		if (system_mode_count % 2 == 0) {
			for (uint8_t i = 0; i < sizeof(order_power_up) / sizeof(order_power_up[0]); i++) {
				if (!relay_state[order_power_up[i]]) {
					relay_set(order_power_up[i], true);
					return;
				}
			}
			system_mode_change(IDLE);
		}
		return;
	}
	
	if (system_mode == POWER_DOWN_WAIT) {
		//SW_08_L01_set_level(system_blink);
		setLED(13, system_blink);
		if (system_mode_count >= 120) {
			system_mode_change(POWER_DOWN);
		}
		return;
	}
	
	if (system_mode == POWER_DOWN) {
		//SW_08_L01_set_level(system_blink);
		setLED(13, system_blink);
		if (system_mode_count % 2 == 0) {
			for (uint8_t i = 0; i < sizeof(order_power_down) / sizeof(order_power_down[0]); i++) {
				if (relay_state[order_power_down[i]]) {
					relay_set(order_power_down[i], false);
					return;
				}
			}
			system_mode_change(IDLE);
		}
		return;
	}
}

// ------------------------------------------------------------------------------------

void button_action(uint8_t btn) {
	printf("Button action %d\n", btn);

	if (btn == 0) {
		if (system_mode == IDLE && power_up_ready()) {
			system_mode_change(POWER_UP);
			return;
		}
		if (system_mode == POWER_DOWN_WAIT) {
			system_mode_change(IDLE);
			return;
		}
		if (system_mode == POWER_DOWN) {
			system_mode_change(IDLE);
			return;
		}
		return;
	}

	if (btn == 1) {
		relay_toggle(0);
		return;
	}

	if (btn == 2) {
		relay_toggle(1);
		return;
	}

	if (btn == 3) {
		pgm_state = 0x00;
		relay_toggle(4);
		return;
	}

	if (btn == 4) {
		if (!relay_state[4]) {
			pgm_state = 0x00;
			relay_set(4, true);
			return;
		}

		//		SW_05_L01_set_level(true);
		setLED(7, true);
		
		pgm_state++;
		if (pgm_state > PGM_STATE_MAX) {
			pgm_state = 0;
		}
		i2c_send = true;
		pgm_flash = 10;
		return;
	}

	if (btn == 5) {
		relay_toggle(2);
		return;
	}

	if (btn == 6) {
		relay_toggle(3);
		return;
	}
	
	if (btn == 7) {
		if (system_mode == IDLE && power_down_ready()) {
			system_mode_change(POWER_DOWN_WAIT);
			return;
		}
		if (system_mode == POWER_UP) {
			system_mode_change(IDLE);
			return;
		}
		if (system_mode == POWER_DOWN_WAIT) {
			system_mode_change(POWER_DOWN);
			return;
		}
		return;
	}
}

// ------------------------------------------------------------------------------------

ISR (TIMER0_OVF_vect) {
	for (uint8_t i = 0; i < 8; i++) {
		if (btn_timeout[i] > 0) {
			btn_timeout[i]--;
			} else {
			if (!(*fp_btn[i])()) {
				btn_timeout[i] = i == 4 ? 10 : 30;
				btn_state[i] = true;
			}
		}
	}
}

ISR(TIMER1_COMPA_vect) {
	system_blink = !system_blink;
	system_mode_tick();
}

ISR(TIMER3_COMPA_vect) {
	test();
}
// ------------------------------------------------------------------------------------

int main(void) {
	
	atmel_start_init();
	
	_delay_ms(500);
	
	printf("\nlight-desk-ctl v0.1 by kiu\n");
	
	SW_01_L01_set_level(true);
	_delay_ms(300);
	SW_02_L01_set_level(true);
	_delay_ms(300);
	SW_03_L01_set_level(true);
	_delay_ms(300);
	SW_04_L01_set_level(true);
	_delay_ms(300);
	SW_05_L01_set_level(true);
	_delay_ms(300);
	SW_06_L01_set_level(true);
	_delay_ms(300);
	SW_07_L01_set_level(true);
	_delay_ms(300);
	
	system_mode_change(IDLE);

	setLED(1, true);
	setLED(3, true);
	setLED(5, true);
	setLED(7, true);
	setLED(9, true);
	setLED(11, true);

	sei();
	
	uint8_t i2c_payload = 0x00;
	
	while(1) {

		for (uint8_t i = 0; i < 8; i++) {
			if (btn_state[i]) {
				btn_state[i] = false;
				button_action(i);
			}
		}

		if (pgm_flash > 0) {
			if (pgm_flash == 1) {
				//SW_05_L01_set_level(!relay_state[4]);
				setLED(7, !relay_state[4]);
			}
			pgm_flash--;
		}
		
		if (i2c_send) {
			i2c_send = false;
			i2c_payload = 0x00;
			i2c_payload |= (relay_state[0] << 0);
			i2c_payload |= (relay_state[1] << 1);
			i2c_payload |= (relay_state[2] << 2);
			i2c_payload |= (relay_state[3] << 3);
			i2c_payload |= (relay_state[4] << 4);
			i2c_payload |= (pgm_state << 5);
			printf("I2C sending payload 0x%02hhX ("BYTE_TO_BINARY_PATTERN") to slave 0x%02hhX\n", i2c_payload, BYTE_TO_BINARY(i2c_payload), I2C_SLAVE);

			i2c_error_t ee;
			while ((ee = I2C_0_write1ByteRegister(0x42, 0x01, i2c_payload)) != I2C_NOERR) {
				if (ee == I2C_BUSY) printf("TWI: BUSY\n");
				if (ee == I2C_FAIL) printf("TWI: FAIL\n");
				_delay_ms(500);
			}
			printf("TWI: OK\n");
		}

		_delay_ms(50);
	}
}

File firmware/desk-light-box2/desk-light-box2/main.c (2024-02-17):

#include <atmel_start.h>
#include <stdio.h>
#include <compat/twi.h>
#include <util/delay.h>
#include "rgb.h"

#define TWI_DEBUG 0

void (*fp_level[5])(const bool) = {RL01_TRIG_set_level, RL02_TRIG_set_level, RL03_TRIG_set_level, RL04_TRIG_set_level, RL05_TRIG_set_level};

uint8_t state_current = 0x00;
uint8_t state_target  = 0x00;

uint8_t relay_timeout_init = 0xFF;
uint8_t relay_timeout[5];

uint8_t val_current;
uint8_t val_target;
uint8_t i;
uint8_t t;

uint8_t twi_buf[2];
uint8_t twi_idx = 0;
bool twi_success = false;

ISR (TIMER0_OVF_vect) {
	for (t = 0; t < 5; t++) {
		if (relay_timeout[t] > 0) {
			relay_timeout[t]--;
		}
	}
}

void update_relay() {
	if ((state_current & 0b00011111) == (state_target & 0b00011111)) {
		return;
	}

	for (i = 0; i < 5; i++) {
		if (relay_timeout[i] > 0) {
			continue;
		}
		
		val_current = (state_current >> i) & 0x01;
		val_target = (state_target >> i) & 0x01;
		if (val_current == val_target) {
			continue;
		}
		
		printf("Relay 0x%02hhX set to 0x%02hhX\n", i, val_target);

		relay_timeout[i] = relay_timeout_init;
		(*fp_level[i])(val_target);
		
		if (i == 4) {
			rgb_enable(val_target);
		}
		state_current = (state_current & ~(0x01 << i)) | (val_target << i);
	}
}

void update_program() {
	if ((state_current & 0b11100000) == (state_target & 0b11100000)) {
		return;
	}

	val_target = state_target >> 5;
	
	printf("Program set to 0x%02hhX\n", val_target);
	
	rgb_pgm_change(val_target);
	
	state_current = (state_current & 0b00011111) | (state_target & 0b11100000);
}

ISR(TWI0_vect) {
	
	switch(TWSR0 & 0xF8) {
		
		// Slave Receiver
		case TW_SR_SLA_ACK:   // addressed, returned ack
		case TW_SR_GCALL_ACK: // addressed generally, returned ack
		case TW_SR_ARB_LOST_SLA_ACK:   // lost arbitration, returned ack
		case TW_SR_ARB_LOST_GCALL_ACK: // lost arbitration, returned ack
		#if TWI_DEBUG
		printf("TWI: TW_SR_SLA_ACK\n");
		#endif
		twi_idx = 0;
		twi_success = true;
		TWCR0 |= (1 << TWINT) | (1 << TWEA); // ACK
		break;
		
		case TW_SR_DATA_ACK:       // data received, returned ack
		case TW_SR_GCALL_DATA_ACK: // data received generally, returned ack
		#if TWI_DEBUG
		printf("TWI: TW_SR_DATA_ACK\n");
		#endif
		if (twi_idx < (sizeof(twi_buf) / sizeof(twi_buf[0]))) {
			#if TWI_DEBUG
			printf("TWI: Send ACK\n");
			#endif
			twi_buf[twi_idx++] = TWDR0;
			TWCR0 |= (1 << TWINT) | (1 << TWEA); // ACK
			} else {
			#if TWI_DEBUG
			printf("TWI: Send NACK\n");
			#endif
			twi_success = false;
			TWCR0 |= (1 << TWINT); // NACK
		}
		break;

		case TW_SR_STOP: // stop or repeated start condition received
		#if TWI_DEBUG
		printf("TWI: TW_SR_STOP\n");
		#endif
		TWCR0 |= (1 << TWINT) | (1 << TWEA); // ACK
		if (twi_success) {
			#if TWI_DEBUG
			printf("TWI: DATA");
			for (uint8_t d = 0; d < twi_idx; d++) {
				printf(" 0x%02hhX", twi_buf[d]);
			}
			printf("\n");
			#endif
			state_target = twi_buf[1];
		}
		break;

		case TW_SR_DATA_NACK:       // data received, returned nack
		case TW_SR_GCALL_DATA_NACK: // data received generally, returned nack
		#if TWI_DEBUG
		printf("TWI: TW_SR_DATA_NACK\n");
		#endif
		TWCR0 |= (1 << TWINT); // NACK
		break;
		
		// All
		case TW_NO_INFO:   // no state information
		break;

		case TW_BUS_ERROR: // bus error, illegal stop/start
		TWCR0 = 0x00;
		_delay_ms(1);
		TWCR0 |= (1 << TWEN) | (1 << TWIE) | (1 << TWEA);
		break;
	}

}

int main(void) {
	
	atmel_start_init();

	_delay_ms(500);

	printf("\nlight-desk-box v0.1 by kiu\n");
	
	TWCR0 |= (1 << TWEN) | (1 << TWIE) | (1 << TWEA);
	
	sei();
	
	while (1) {		
		if (state_current != state_target) {
			update_relay();
			update_program();
		}

		rgb_tick();
		
		_delay_ms(10);
	}
}

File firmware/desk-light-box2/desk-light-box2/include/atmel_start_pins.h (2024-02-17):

/*
 * Code generated from Atmel Start.
 *
 * This file will be overwritten when reconfiguring your Atmel Start project.
 * Please copy examples or other code you want to keep to a separate file
 * to avoid losing it when reconfiguring.
 */
#ifndef ATMEL_START_PINS_H_INCLUDED
#define ATMEL_START_PINS_H_INCLUDED

#include <port.h>

/**
 * \brief Set PB3 pull mode
 *
 * Configure pin to pull up, down or disable pull mode, supported pull
 * modes are defined by device used
 *
 * \param[in] pull_mode Pin pull mode
 */
static inline void PB3_set_pull_mode(const enum port_pull_mode pull_mode)
{
	PORTB_set_pin_pull_mode(3, pull_mode);
}

/**
 * \brief Set PB3 data direction
 *
 * Select if the pin data direction is input, output or disabled.
 * If disabled state is not possible, this function throws an assert.
 *
 * \param[in] direction PORT_DIR_IN  = Data direction in
 *                      PORT_DIR_OUT = Data direction out
 *                      PORT_DIR_OFF = Disables the pin
 *                      (low power state)
 */
static inline void PB3_set_dir(const enum port_dir dir)
{
	PORTB_set_pin_dir(3, dir);
}

/**
 * \brief Set PB3 level
 *
 * Sets output level on a pin
 *
 * \param[in] level true  = Pin level set to "high" state
 *                  false = Pin level set to "low" state
 */
static inline void PB3_set_level(const bool level)
{
	PORTB_set_pin_level(3, level);
}

/**
 * \brief Toggle output level on PB3
 *
 * Toggle the pin level
 */
static inline void PB3_toggle_level()
{
	PORTB_toggle_pin_level(3);
}

/**
 * \brief Get level on PB3
 *
 * Reads the level on a pin
 */
static inline bool PB3_get_level()
{
	return PORTB_get_pin_level(3);
}

/**
 * \brief Set PB4 pull mode
 *
 * Configure pin to pull up, down or disable pull mode, supported pull
 * modes are defined by device used
 *
 * \param[in] pull_mode Pin pull mode
 */
static inline void PB4_set_pull_mode(const enum port_pull_mode pull_mode)
{
	PORTB_set_pin_pull_mode(4, pull_mode);
}

/**
 * \brief Set PB4 data direction
 *
 * Select if the pin data direction is input, output or disabled.
 * If disabled state is not possible, this function throws an assert.
 *
 * \param[in] direction PORT_DIR_IN  = Data direction in
 *                      PORT_DIR_OUT = Data direction out
 *                      PORT_DIR_OFF = Disables the pin
 *                      (low power state)
 */
static inline void PB4_set_dir(const enum port_dir dir)
{
	PORTB_set_pin_dir(4, dir);
}

/**
 * \brief Set PB4 level
 *
 * Sets output level on a pin
 *
 * \param[in] level true  = Pin level set to "high" state
 *                  false = Pin level set to "low" state
 */
static inline void PB4_set_level(const bool level)
{
	PORTB_set_pin_level(4, level);
}

/**
 * \brief Toggle output level on PB4
 *
 * Toggle the pin level
 */
static inline void PB4_toggle_level()
{
	PORTB_toggle_pin_level(4);
}

/**
 * \brief Get level on PB4
 *
 * Reads the level on a pin
 */
static inline bool PB4_get_level()
{
	return PORTB_get_pin_level(4);
}

/**
 * \brief Set PB5 pull mode
 *
 * Configure pin to pull up, down or disable pull mode, supported pull
 * modes are defined by device used
 *
 * \param[in] pull_mode Pin pull mode
 */
static inline void PB5_set_pull_mode(const enum port_pull_mode pull_mode)
{
	PORTB_set_pin_pull_mode(5, pull_mode);
}

/**
 * \brief Set PB5 data direction
 *
 * Select if the pin data direction is input, output or disabled.
 * If disabled state is not possible, this function throws an assert.
 *
 * \param[in] direction PORT_DIR_IN  = Data direction in
 *                      PORT_DIR_OUT = Data direction out
 *                      PORT_DIR_OFF = Disables the pin
 *                      (low power state)
 */
static inline void PB5_set_dir(const enum port_dir dir)
{
	PORTB_set_pin_dir(5, dir);
}

/**
 * \brief Set PB5 level
 *
 * Sets output level on a pin
 *
 * \param[in] level true  = Pin level set to "high" state
 *                  false = Pin level set to "low" state
 */
static inline void PB5_set_level(const bool level)
{
	PORTB_set_pin_level(5, level);
}

/**
 * \brief Toggle output level on PB5
 *
 * Toggle the pin level
 */
static inline void PB5_toggle_level()
{
	PORTB_toggle_pin_level(5);
}

/**
 * \brief Get level on PB5
 *
 * Reads the level on a pin
 */
static inline bool PB5_get_level()
{
	return PORTB_get_pin_level(5);
}

/**
 * \brief Set PC4 pull mode
 *
 * Configure pin to pull up, down or disable pull mode, supported pull
 * modes are defined by device used
 *
 * \param[in] pull_mode Pin pull mode
 */
static inline void PC4_set_pull_mode(const enum port_pull_mode pull_mode)
{
	PORTC_set_pin_pull_mode(4, pull_mode);
}

/**
 * \brief Set PC4 data direction
 *
 * Select if the pin data direction is input, output or disabled.
 * If disabled state is not possible, this function throws an assert.
 *
 * \param[in] direction PORT_DIR_IN  = Data direction in
 *                      PORT_DIR_OUT = Data direction out
 *                      PORT_DIR_OFF = Disables the pin
 *                      (low power state)
 */
static inline void PC4_set_dir(const enum port_dir dir)
{
	PORTC_set_pin_dir(4, dir);
}

/**
 * \brief Set PC4 level
 *
 * Sets output level on a pin
 *
 * \param[in] level true  = Pin level set to "high" state
 *                  false = Pin level set to "low" state
 */
static inline void PC4_set_level(const bool level)
{
	PORTC_set_pin_level(4, level);
}

/**
 * \brief Toggle output level on PC4
 *
 * Toggle the pin level
 */
static inline void PC4_toggle_level()
{
	PORTC_toggle_pin_level(4);
}

/**
 * \brief Get level on PC4
 *
 * Reads the level on a pin
 */
static inline bool PC4_get_level()
{
	return PORTC_get_pin_level(4);
}

/**
 * \brief Set PC5 pull mode
 *
 * Configure pin to pull up, down or disable pull mode, supported pull
 * modes are defined by device used
 *
 * \param[in] pull_mode Pin pull mode
 */
static inline void PC5_set_pull_mode(const enum port_pull_mode pull_mode)
{
	PORTC_set_pin_pull_mode(5, pull_mode);
}

/**
 * \brief Set PC5 data direction
 *
 * Select if the pin data direction is input, output or disabled.
 * If disabled state is not possible, this function throws an assert.
 *
 * \param[in] direction PORT_DIR_IN  = Data direction in
 *                      PORT_DIR_OUT = Data direction out
 *                      PORT_DIR_OFF = Disables the pin
 *                      (low power state)
 */
static inline void PC5_set_dir(const enum port_dir dir)
{
	PORTC_set_pin_dir(5, dir);
}

/**
 * \brief Set PC5 level
 *
 * Sets output level on a pin
 *
 * \param[in] level true  = Pin level set to "high" state
 *                  false = Pin level set to "low" state
 */
static inline void PC5_set_level(const bool level)
{
	PORTC_set_pin_level(5, level);
}

/**
 * \brief Toggle output level on PC5
 *
 * Toggle the pin level
 */
static inline void PC5_toggle_level()
{
	PORTC_toggle_pin_level(5);
}
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

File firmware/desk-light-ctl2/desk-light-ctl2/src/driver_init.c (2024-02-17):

/**
 * \file
 *
 * \brief Driver initialization.
 *
 (c) 2020 Microchip Technology Inc. and its subsidiaries.

    Subject to your compliance with these terms,you may use this software and
    any derivatives exclusively with Microchip products.It is your responsibility
    to comply with third party license terms applicable to your use of third party
    software (including open source software) that may accompany Microchip software.

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
    IN NO EVENT WILL MICROCHIP BE LIABLE FOR ANY INDIRECT, SPECIAL, PUNITIVE,
    INCIDENTAL OR CONSEQUENTIAL LOSS, DAMAGE, COST OR EXPENSE OF ANY KIND
    WHATSOEVER RELATED TO THE SOFTWARE, HOWEVER CAUSED, EVEN IF MICROCHIP HAS
    BEEN ADVISED OF THE POSSIBILITY OR THE DAMAGES ARE FORESEEABLE. TO THE
    FULLEST EXTENT ALLOWED BY LAW, MICROCHIP'S TOTAL LIABILITY ON ALL CLAIMS IN
    ANY WAY RELATED TO THIS SOFTWARE WILL NOT EXCEED THE AMOUNT OF FEES, IF ANY,
    THAT YOU HAVE PAID DIRECTLY TO MICROCHIP FOR THIS SOFTWARE.
 *
 */

/*
 * Code generated by START.
 *
 * This file will be overwritten when reconfiguring your START project.
 * Please copy examples or other code you want to keep to a separate file
 * to avoid losing it when reconfiguring.
 */

#include "driver_init.h"
#include <system.h>

/* configure pins and initialize registers */
void I2C_0_initialization(void)
{

	PC5_set_dir(
	    // <y> Pin direction
	    // <id> pad_dir
	    // <PORT_DIR_OFF"> Off
	    // <PORT_DIR_IN"> In
	    // <PORT_DIR_OUT"> Out
	    PORT_DIR_OUT);

	PC5_set_level(
	    // <y> Initial level
	    // <id> pad_initial_level
	    // <false"> Low
	    // <true"> High
	    false);

	PC5_set_pull_mode(
	    // <y> Pull configuration
	    // <id> pad_pull_config
	    // <PORT_PULL_OFF"> Off
	    // <PORT_PULL_UP"> Pull-up
	    PORT_PULL_OFF);

	PC4_set_dir(
	    // <y> Pin direction
	    // <id> pad_dir
	    // <PORT_DIR_OFF"> Off
	    // <PORT_DIR_IN"> In
	    // <PORT_DIR_OUT"> Out
	    PORT_DIR_OUT);

	PC4_set_level(
	    // <y> Initial level
	    // <id> pad_initial_level
	    // <false"> Low
	    // <true"> High
	    false);

	PC4_set_pull_mode(
	    // <y> Pull configuration
	    // <id> pad_pull_config
	    // <PORT_PULL_OFF"> Off
	    // <PORT_PULL_UP"> Pull-up
	    PORT_PULL_OFF);

	I2C_0_init();
}

void TIMER_0_initialization(void)
{

	TIMER_0_init();
}

void TIMER_1_initialization(void)
{

	TIMER_1_init();
}

void TIMER_2_initialization(void)
{

	TIMER_2_init();
}

/* configure pins and initialize registers */
void USART_0_initialization(void)
{

	// Set pin direction to input
	PD0_set_dir(PORT_DIR_IN);

	PD0_set_pull_mode(
	    // <y> Pull configuration
	    // <id> pad_pull_config
	    // <PORT_PULL_OFF"> Off
	    // <PORT_PULL_UP"> Pull-up
	    PORT_PULL_OFF);

	// Set pin direction to output
	PD1_set_dir(PORT_DIR_OUT);

	PD1_set_level(
	    // <y> Initial level
	    // <id> pad_initial_level
	    // <false"> Low
	    // <true"> High
	    false);

	USART_0_init();
}

/**
 * \brief System initialization
 */
void system_init()
{
	mcu_init();

	/* PORT setting on PB0 */

	// Set pin direction to input
	SW_05_BTN_set_dir(PORT_DIR_IN);

	SW_05_BTN_set_pull_mode(
	    // <y> Pull configuration
	    // <id> pad_pull_config
	    // <PORT_PULL_OFF"> Off
	    // <PORT_PULL_UP"> Pull-up
	    PORT_PULL_UP);

	/* PORT setting on PB1 */

	// Set pin direction to output
	SW_04_L02_set_dir(PORT_DIR_OUT);

	SW_04_L02_set_level(
	    // <y> Initial level
	    // <id> pad_initial_level
	    // <false"> Low
	    // <true"> High
	    false);

	/* PORT setting on PB2 */

	// Set pin direction to output
	SW_04_L01_set_dir(PORT_DIR_OUT);

	SW_04_L01_set_level(
	    // <y> Initial level
	    // <id> pad_initial_level
	    // <false"> Low
	    // <true"> High
	    false);

	/* PORT setting on PB3 */

	// Set pin direction to input
	SW_04_BTN_set_dir(PORT_DIR_IN);

	SW_04_BTN_set_pull_mode(
	    // <y> Pull configuration
	    // <id> pad_pull_config
	    // <PORT_PULL_OFF"> Off
	    // <PORT_PULL_UP"> Pull-up
	    PORT_PULL_UP);

	/* PORT setting on PB4 */

	// Set pin direction to output
	SW_03_L02_set_dir(PORT_DIR_OUT);

	SW_03_L02_set_level(
	    // <y> Initial level
	    // <id> pad_initial_level
	    // <false"> Low
	    // <true"> High
	    false);

	/* PORT setting on PB5 */

	// Set pin direction to output
	SW_03_L01_set_dir(PORT_DIR_OUT);

	SW_03_L01_set_level(
	    // <y> Initial level
	    // <id> pad_initial_level
	    // <false"> Low
	    // <true"> High
	    false);

	/* PORT setting on PB6 */

	// Set pin direction to output
	SW_06_L02_set_dir(PORT_DIR_OUT);

	SW_06_L02_set_level(
	    // <y> Initial level
	    // <id> pad_initial_level
	    // <false"> Low
	    // <true"> High
	    false);

	/* PORT setting on PB7 */

	// Set pin direction to output
	SW_06_L01_set_dir(PORT_DIR_OUT);

	SW_06_L01_set_level(
	    // <y> Initial level
	    // <id> pad_initial_level
	    // <false"> Low
	    // <true"> High
	    false);

	/* PORT setting on PC0 */

	// Set pin direction to output
	SW_02_L01_set_dir(PORT_DIR_OUT);

	SW_02_L01_set_level(
	    // <y> Initial level
	    // <id> pad_initial_level
	    // <false"> Low
	    // <true"> High
	    false);

	/* PORT setting on PC1 */

	// Set pin direction to input
	SW_02_BTN_set_dir(PORT_DIR_IN);

	SW_02_BTN_set_pull_mode(
	    // <y> Pull configuration
	    // <id> pad_pull_config
	    // <PORT_PULL_OFF"> Off
	    // <PORT_PULL_UP"> Pull-up
	    PORT_PULL_UP);

	/* PORT setting on PC2 */

	// Set pin direction to input
	SW_01_BTN_set_dir(PORT_DIR_IN);

	SW_01_BTN_set_pull_mode(
	    // <y> Pull configuration
	    // <id> pad_pull_config
	    // <PORT_PULL_OFF"> Off
	    // <PORT_PULL_UP"> Pull-up
	    PORT_PULL_UP);

	/* PORT setting on PC3 */

	// Set pin direction to output
	SW_01_L01_set_dir(PORT_DIR_OUT);

	SW_01_L01_set_level(
	    // <y> Initial level
	    // <id> pad_initial_level
	    // <false"> Low
	    // <true"> High
	    false);

	/* PORT setting on PD2 */

	// Set pin direction to input
	SW_08_BTN_set_dir(PORT_DIR_IN);

	SW_08_BTN_set_pull_mode(
	    // <y> Pull configuration
	    // <id> pad_pull_config
	    // <PORT_PULL_OFF"> Off
	    // <PORT_PULL_UP"> Pull-up
	    PORT_PULL_UP);

	/* PORT setting on PD3 */

	// Set pin direction to output
	SW_08_L01_set_dir(PORT_DIR_OUT);

	SW_08_L01_set_level(
	    // <y> Initial level
	    // <id> pad_initial_level
	    // <false"> Low
	    // <true"> High
	    false);

	/* PORT setting on PD4 */

	// Set pin direction to output
	SW_07_L02_set_dir(PORT_DIR_OUT);

	SW_07_L02_set_level(
	    // <y> Initial level
	    // <id> pad_initial_level
	    // <false"> Low
	    // <true"> High
	    false);

	/* PORT setting on PD5 */

	// Set pin direction to input
	SW_06_BTN_set_dir(PORT_DIR_IN);

	SW_06_BTN_set_pull_mode(
	    // <y> Pull configuration
	    // <id> pad_pull_config
	    // <PORT_PULL_OFF"> Off
	    // <PORT_PULL_UP"> Pull-up
	    PORT_PULL_UP);

	/* PORT setting on PD6 */

	// Set pin direction to output
	SW_05_L02_set_dir(PORT_DIR_OUT);
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
